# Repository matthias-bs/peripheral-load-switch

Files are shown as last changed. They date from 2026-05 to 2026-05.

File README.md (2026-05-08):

# peripheral-load-switch



Compact SMD peripheral load switch based on the Vishay SiP32431, designed for enabling/disabling power to microcontroller peripherals.

## Description

A minimal, all-SMD load switch board for switching a peripheral's supply voltage under microcontroller control. The design uses the Vishay **SiP32431DR3** high-side switch in a SC-70-6 (SOT-363) package. Board-edge castellated contacts (J2, half-hole, DNP) allow direct PCB-to-PCB soldering or surface mounting. An optional 5-pin 2.54 mm pitch pin header (J1) provides access for prototyping with breadboards or Dupont wires.

## SiP32431 Key Specifications

Datasheet: [SiP32431 (Vishay, PDF)](https://www.vishay.com/docs/66597/sip32431.pdf)

| Parameter | Value |
|---|---|
| Operating voltage | 1.5 V – 5.5 V |
| Max continuous current  | 1.2 A |
| R<sub>DS(on)</sub> | 147 mΩ |
| Package | SC-70-6 (JEITA) / SOT-363 (JEDEC)  |
| Enable logic | Active-high |
| Switch type | High-side |
| Leakage current | 10 pA (ultra-low) |
| Special features | Reverse current blocking, soft-start, ultra-low quiescent current |

## PCB & Schematic Features

- All-SMD design; 0805 passives are (more or less) hand-solderable, SC-70-6 IC requires reflow soldering
- 1 MΩ pull-down on EN pin ensures switch-off when enable is floating
- 1 µF input and 100 nF output decoupling capacitors
- 5-pin 2.54 mm pitch half-hole edge connector (J2, DNP) — castellated board-edge contacts for PCB-to-PCB or surface mounting
- 5-pin 2.54 mm pitch pin header (J1, optional) — for PCB-to-PCB stacking or prototyping with breadboards or Dupont wires
- DRC-clean design (0 violations, 0 unconnected pads)
- KiCad 9 source files with custom `Edge_HalfHole_5Pin_2.54mm` footprint included

## Schematic Preview

Schematic (https://kicanvas.org/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)

*Click image to open interactive schematic viewer (KiCanvas)*

## Interactive 3D PCB View

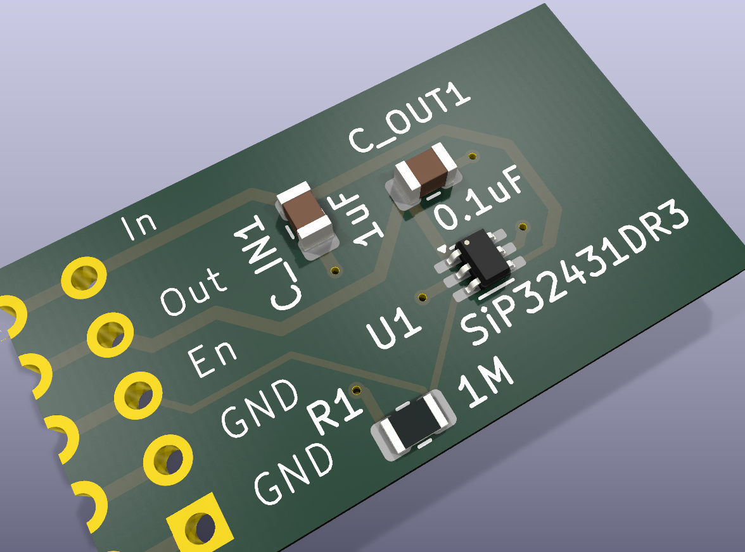
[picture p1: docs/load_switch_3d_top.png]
3D PCB render (https://matthias-bs.github.io/peripheral-load-switch/)


*Click image to open the interactive 3D model viewer (rotate/zoom/pan) — or use [KiCanvas](https://kicanvas.org/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) for a full PCB layer inspector*

> **How it was generated:** The 3D model ([`docs/load_switch.glb`](docs/load_switch.glb)) was exported from KiCad 9 using `kicad-cli pcb export glb` with tracks, pads, zones, silkscreen and soldermask included. The viewer ([`docs/index.html`](docs/index.html)) is a custom [Three.js](https://threejs.org/) page served via GitHub Pages.

## Bill of Materials

| Ref | Value | Footprint | Description | LCSC Part # |
|---|---|---|---|---|
| U1 | SiP32431DR3 | SC-70-6 (SOT-363)| High-side load switch | [C141606](https://www.lcsc.com/product-detail/C141606.html) |
| R1 | 1 MΩ | 0805 | Pull-down on EN pin | [C17514](https://www.lcsc.com/product-detail/C17514.html)  |
| C_IN1 | 1 µF | 0805 | Input decoupling capacitor | [C1712](https://www.lcsc.com/product-detail/C1712.html) |
| C_OUT1 | 100 nF | 0805 | Output decoupling capacitor | [C126469](https://www.lcsc.com/product-detail/C126469.html) |
| J1 | — | PinSocket 1×5 2.54 mm | Optional pin header | — |
| J2 | — | Half-hole 5-pin 2.54 mm (DNP¹) | Edge connector | — |

> ¹ DNP = Do Not Populate — the half-hole edge connector (J2) is a PCB manufacturing feature: the through-holes are routed in half at the board edge to form castellated contacts. No separate component is soldered.
>
> LCSC Part # are ordering references for [lcsc.com](https://lcsc.com).

## Connector Pinout (J2 — half-hole edge connector)

| Pin | Signal | Description |
|-----|---|---|
| 1 | GND | Ground |
| 2 | GND | Ground |
| 3 | EN | Enable (active-high) |
| 4 | OUT | Switched output |
| 5 | IN | Supply voltage input |

## Production Files

Ready-to-order Gerber files (standard RS-274X, compatible with any PCB fab) are in the [`production/`](production/) folder.

## License

Copyright 2026 Matthias Prinke

`SPDX-License-Identifier: Apache-2.0 WITH SHL-2.1`

Licensed under the [Solderpad Hardware License v2.1](https://solderpad.org/licenses/SHL-2.1/). See [LICENSE](LICENSE) for the full text.

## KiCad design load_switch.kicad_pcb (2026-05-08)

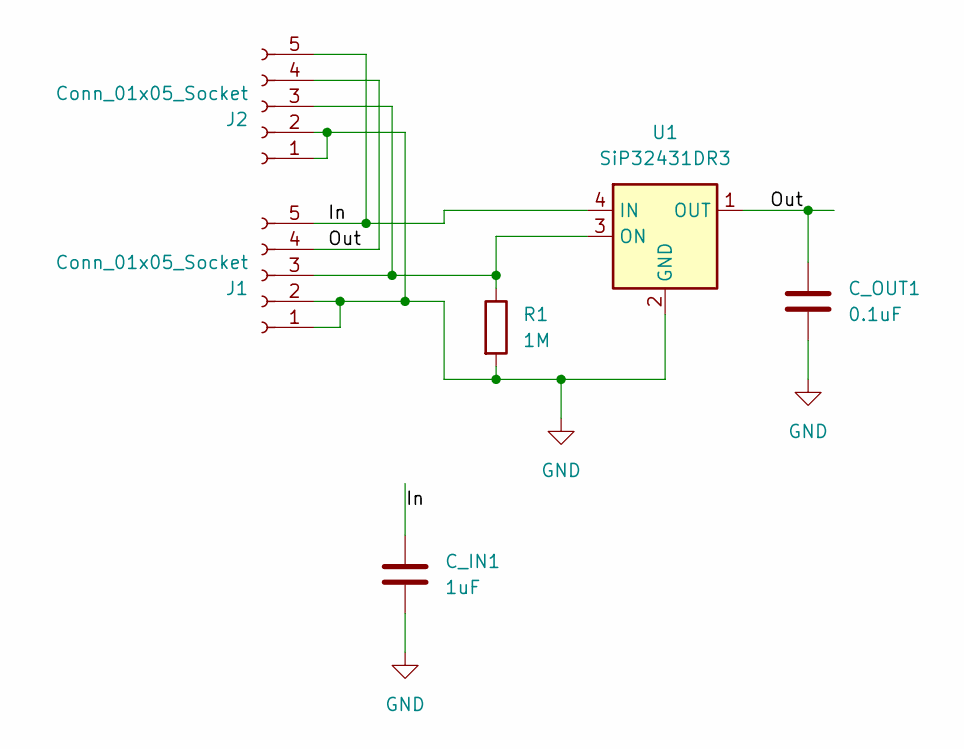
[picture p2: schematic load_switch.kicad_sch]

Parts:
C_IN1: 1uF; C_0805_2012Metric
C_OUT1: 0.1uF; C_0805_2012Metric
J1: Conn_01x05_Socket; PinSocket_1x05_P2.54mm_Vertical
J2: Conn_01x05_Socket; Edge_HalfHole_5Pin_2.54mm
R1: 1M; R_0805_2012Metric
U1: SiP32431DR3; SOT-363_SC-70-6

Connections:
/In: C_IN1.1, J1.5, J2.5, U1.4 (IN)
/Out: C_OUT1.1, J1.4, J2.4, U1.1 (OUT)
GND: C_IN1.2, C_OUT1.2, J1.1, J1.2, J2.1, J2.2, R1.2, U1.2 (GND), U1.5 (GND)
unnamed: J1.3, J2.3, R1.1, U1.3 (ON)

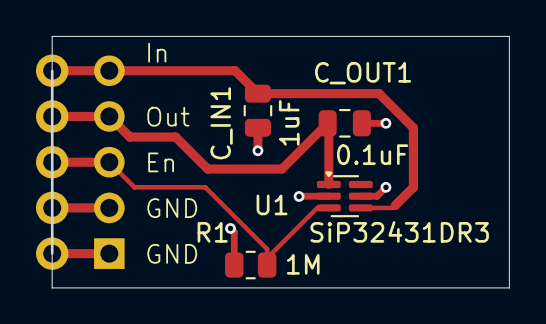
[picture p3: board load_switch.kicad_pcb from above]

Board: 2 copper layers, 25.4 x 14.0 mm, 6 parts (1 on the bottom side), 4 nets.

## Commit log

2026-05-08 Initial release: SiP32431-based load switch, v0.1.0
    [load_switch.kicad_pcb, load_switch.kicad_sch]
2026-05-08 Fix connector pinout and hand-solderable remark in README
2026-05-08 BOM: clarify LCSC Part # column with links and explanatory note
2026-05-08 Add 3D render of PCB and embed as clickable KiCanvas link in README
2026-05-08 Fix initial 3D view: correct camera for Z-up KiCad GLB orientation
2026-05-08 Fix J1/J2 swap in BOM; correct DNP footnote for half-hole edge connector
2026-05-08 Fix silkscreen Z-fighting: enable logarithmic depth buffer
2026-05-08 Fix Z-fighting: apply polygon offset per PCB layer (silk/mask/copper)
2026-05-08 Add note on 3D PCB view generation method
2026-05-08 Clarify hand-solderability of 0805 passives in README.md
2026-05-08 Fix connector descriptions: clarify J1 (optional pin header) and J2 (DNP castellated contacts)
2026-05-08 Update J1 description: clarify usage for PCB-to-PCB stacking and prototyping

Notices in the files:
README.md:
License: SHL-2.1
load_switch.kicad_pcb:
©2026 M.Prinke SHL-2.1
